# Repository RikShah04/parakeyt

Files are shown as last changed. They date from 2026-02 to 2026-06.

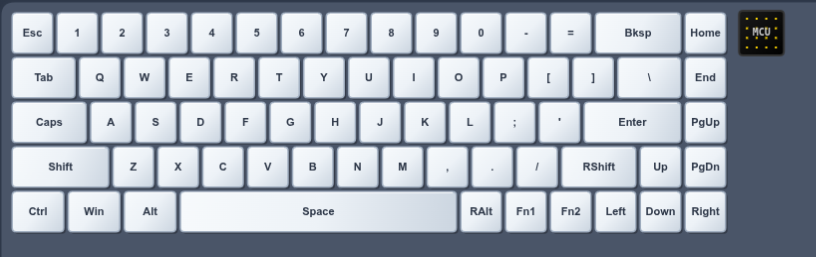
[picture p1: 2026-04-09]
example-boards/tkl/editor.png

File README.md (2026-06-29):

# parakeyt-docs
Ergonomic keyboard generator — PCB, firmware, and case file generation

# structure

## `reference-design/`
contains a completed reference design to act as a testing platform and schematic example of a potential parakeyt board.

it is hand designed, placed, and routed. it is not an actual output of the parakeyt toolchain.

# attribution
Footprints, models, symbols:
- RP2040-zero from https://github.com/crides/kleeb/ (MIT License)
- TLC59108IRGYR from manufacturer
- TLA2528IRTER from manufacturer
- AH49FNTR-G1 from manufacturer

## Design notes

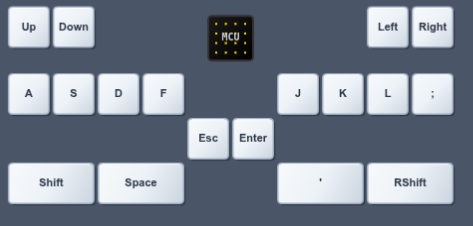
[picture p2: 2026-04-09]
example-boards/sdvx/sdvx.png

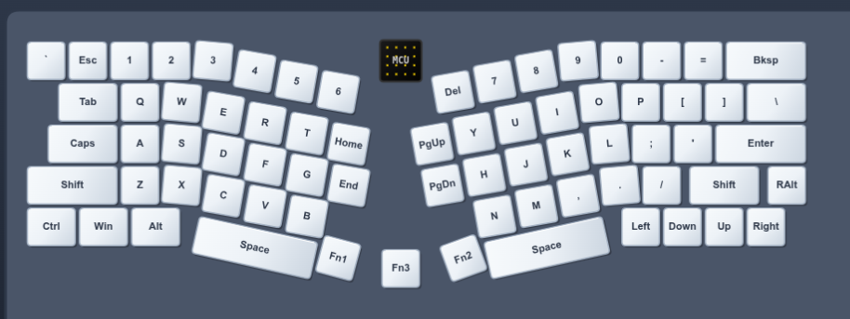
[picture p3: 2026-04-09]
example-boards/alice/alice.png

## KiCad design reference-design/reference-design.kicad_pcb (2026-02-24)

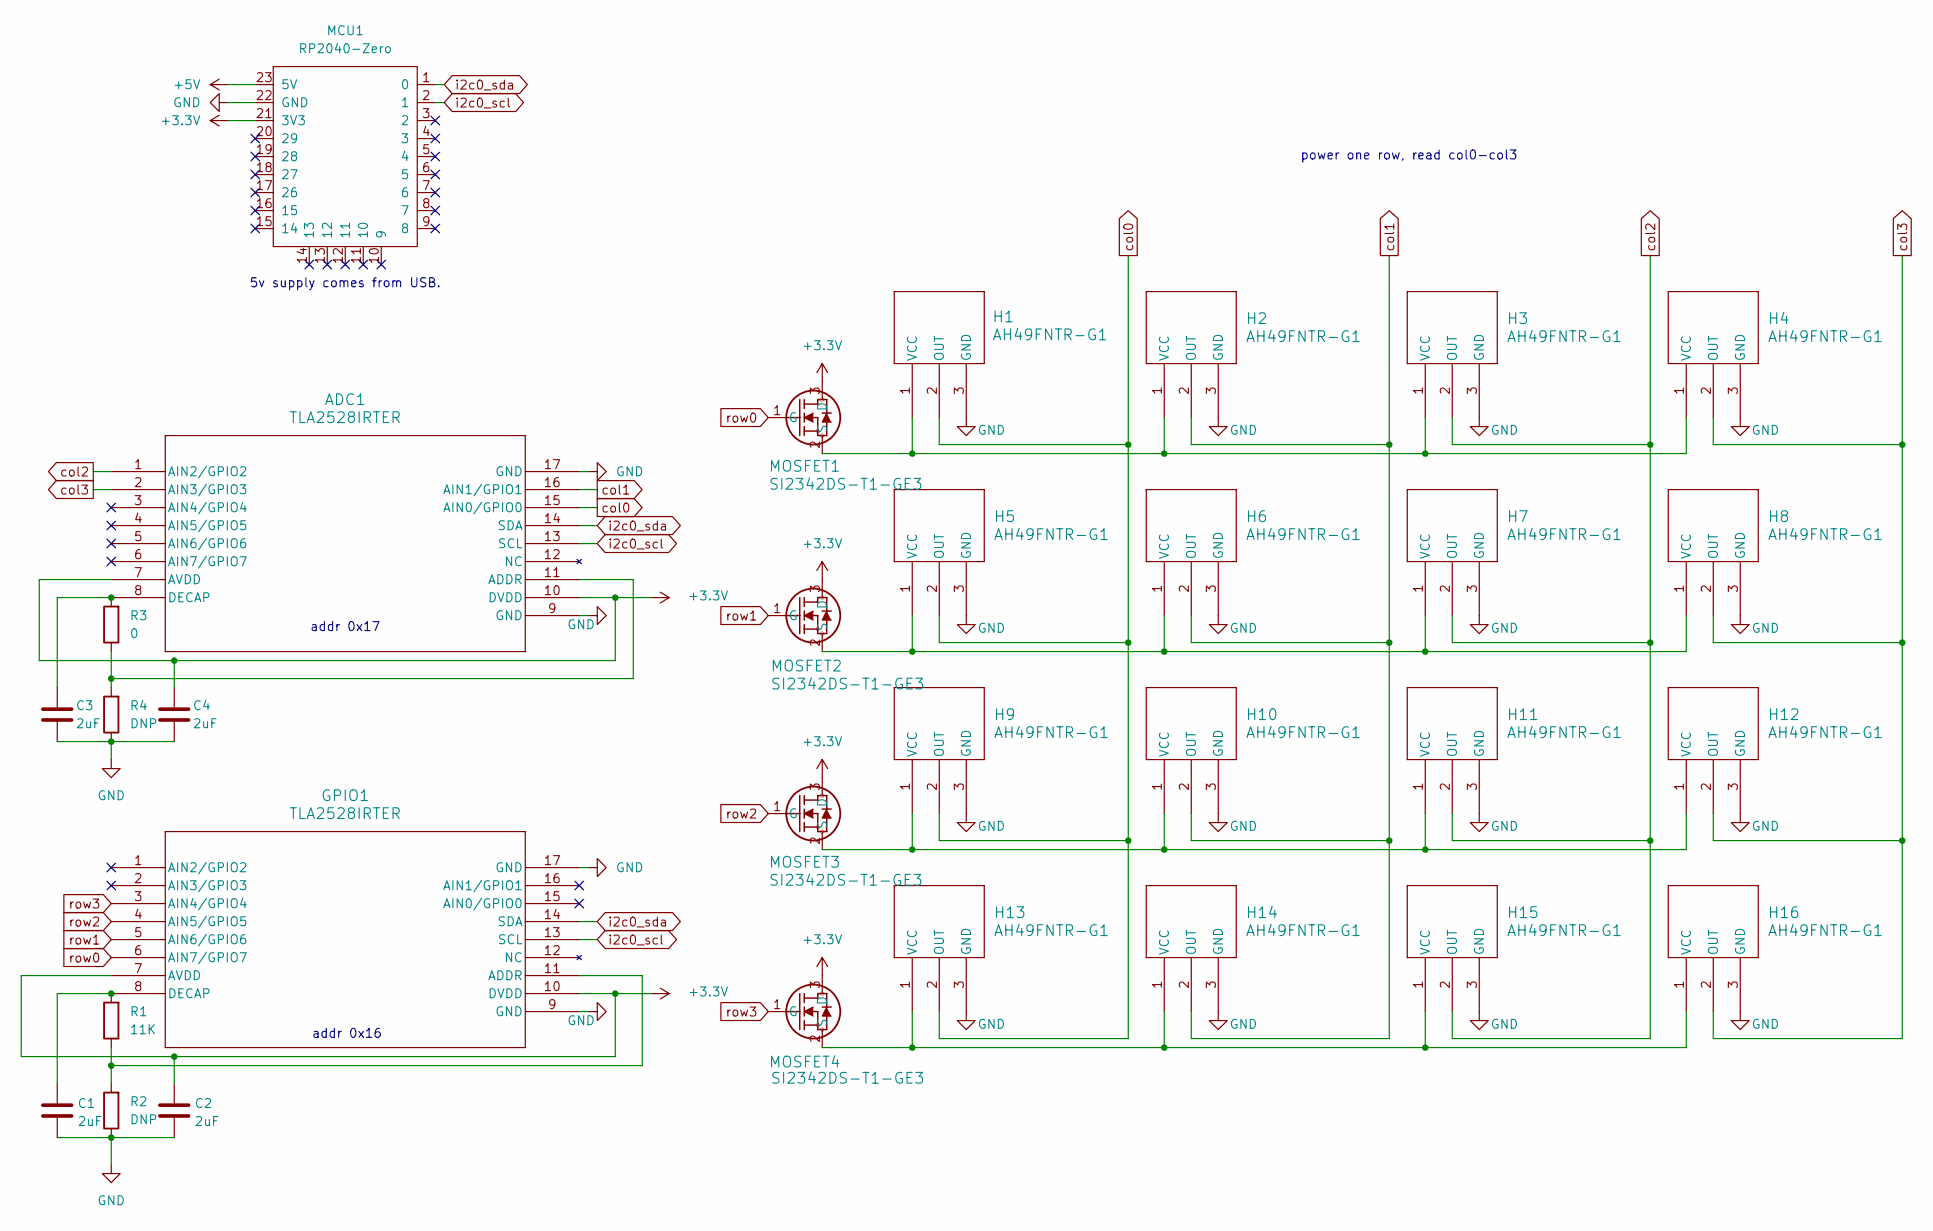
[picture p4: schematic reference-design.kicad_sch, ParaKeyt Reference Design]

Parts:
ADC1: TLA2528IRTER; WQFN16_RTE_TEX
C1, C2, C3, C4: 2uF; C_0603_1608Metric
GPIO1: TLA2528IRTER; WQFN16_RTE_TEX
H1, H2, H3, H4, H5, H6, H7, H8, H9, H10, H11, H12, H13, H14, H15, H16: AH49FNTR-G1; SC59_DIO
MCU1: RP2040-Zero; rp2040-zero-tht
MOSFET1, MOSFET2, MOSFET3, MOSFET4: SI2342DS-T1-GE3; SOT-23_TO-236_VIS
R1: 11K; R_0603_1608Metric
R2, R4: DNP; R_0603_1608Metric
R3: 0; R_0603_1608Metric

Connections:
+3.3V: ADC1.7 (AVDD), ADC1.10 (DVDD), C2.1, C4.1, GPIO1.7 (AVDD), GPIO1.10 (DVDD), MCU1.21 (3V3), MOSFET1.3 (D), MOSFET2.3 (D), MOSFET3.3 (D), MOSFET4.3 (D)
+5V: MCU1.23 (5V)
GND: ADC1.9 (GND), ADC1.17 (GND), C1.2, C2.2, C3.2, C4.2, GPIO1.9 (GND), GPIO1.17 (GND), H1.3 (GND), H2.3 (GND), H3.3 (GND), H4.3 (GND), H5.3 (GND), H6.3 (GND), H7.3 (GND), H8.3 (GND), H9.3 (GND), H10.3 (GND), H11.3 (GND), H12.3 (GND), H13.3 (GND), H14.3 (GND), H15.3 (GND), H16.3 (GND), MCU1.22 (GND), R2.1, R4.1
unnamed: ADC1.11 (ADDR), R3.1, R4.2
unnamed: ADC1.8 (DECAP), C3.1, R3.2
unnamed: GPIO1.11 (ADDR), R1.1, R2.2
unnamed: C1.1, GPIO1.8 (DECAP), R1.2
unnamed: H1.1 (VCC), H2.1 (VCC), H3.1 (VCC), H4.1 (VCC), MOSFET1.2 (S)
unnamed: H5.1 (VCC), H6.1 (VCC), H7.1 (VCC), H8.1 (VCC), MOSFET2.2 (S)
unnamed: H9.1 (VCC), H10.1 (VCC), H11.1 (VCC), H12.1 (VCC), MOSFET3.2 (S)
unnamed: H13.1 (VCC), H14.1 (VCC), H15.1 (VCC), H16.1 (VCC), MOSFET4.2 (S)
col0: ADC1.15 (AIN0/GPIO0), H1.2 (OUT), H5.2 (OUT), H9.2 (OUT), H13.2 (OUT)
col1: ADC1.16 (AIN1/GPIO1), H2.2 (OUT), H6.2 (OUT), H10.2 (OUT), H14.2 (OUT)
col2: ADC1.1 (AIN2/GPIO2), H3.2 (OUT), H7.2 (OUT), H11.2 (OUT), H15.2 (OUT)
col3: ADC1.2 (AIN3/GPIO3), H4.2 (OUT), H8.2 (OUT), H12.2 (OUT), H16.2 (OUT)
i2c0_scl: ADC1.13 (SCL), GPIO1.13 (SCL), MCU1.2 (1)
i2c0_sda: ADC1.14 (SDA), GPIO1.14 (SDA), MCU1.1 (0)
row0: GPIO1.6 (AIN7/GPIO7), MOSFET1.1 (G)
row1: GPIO1.5 (AIN6/GPIO6), MOSFET2.1 (G)
row2: GPIO1.4 (AIN5/GPIO5), MOSFET3.1 (G)
row3: GPIO1.3 (AIN4/GPIO4), MOSFET4.1 (G)

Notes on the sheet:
addr 0x16
addr 0x17
5v supply comes from USB.
power one row, read col0-col3

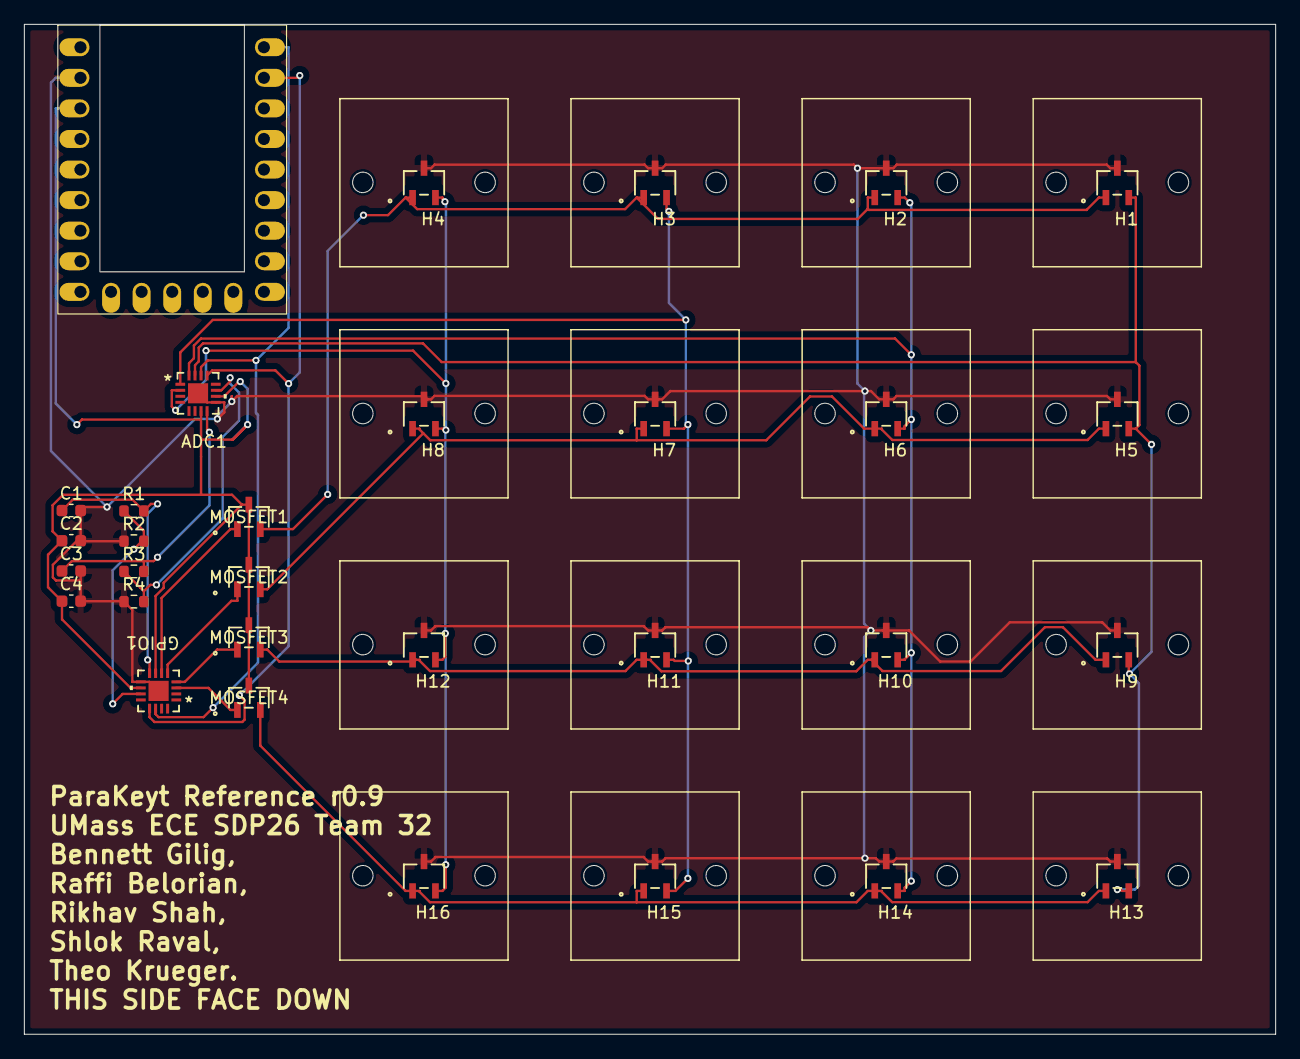
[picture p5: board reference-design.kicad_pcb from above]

Board: 2 copper layers, 104.0 x 83.9 mm, 31 parts (0 on the bottom side), 20 nets.

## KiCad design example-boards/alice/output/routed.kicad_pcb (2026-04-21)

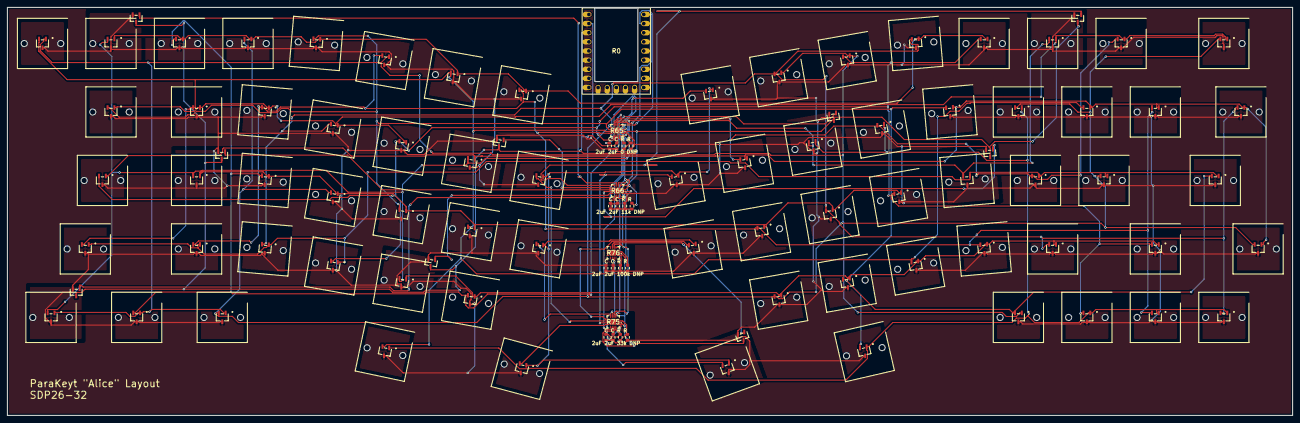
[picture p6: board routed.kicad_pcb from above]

Board: 2 copper layers, 357.5 x 113.5 mm, 76 parts (0 on the bottom side), 43 nets.

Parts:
R0: rp2040-zero-tht
R1, R9, R17, R25, R33, R41, R49, R57, R67: SC59_DIO_KeyswitchOutline_NoRuleArea_mosfet
R2, R3, R4, R5, R6, R7, R8, R10, R11, R12, R13, R14, R15, R16, R18, R19, R20, R21, R22, R23, R24, R26, R27, R28, R29, R30, R31, R32, R34, R35, R36, R37, R38, R39, R40, R42, R43, R44, R45, R46, R47, R48, R50, R51, R52, R53, R54, R55, R56, R58, R59, R60, R61, R62, R63, R64, R68, R69, R70, R71, R72, R74: SC59_DIO_KeyswitchOutline_NoRuleArea_mosfet; SC59_DIO_KeyswitchOutline_NoRuleArea
R65, R66, R75, R76: WQFN16_RTE_TEX_with_caps_and_Rs

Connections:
+3.3v: R0.21, R1.6, R9.6, R17.6, R25.6, R33.6, R41.6, R49.6, R57.6, R65.7, R65.10, R65.20, R66.7, R66.10, R67.6, R75.7, R75.10, R75.20, R76.7, R76.10
GND: R0.22, R1.3, R1.5, R2.3, R3.3, R4.3, R5.3, R6.3, R7.3, R8.3, R9.3, R9.5, R10.3, R11.3, R12.3, R13.3, R14.3, R15.3, R16.3, R17.3, R17.5, R18.3, R19.3, R20.3, R21.3, R22.3, R23.3, R24.3, R25.3, R25.5, R26.3, R27.3, R28.3, R29.3, R30.3, R31.3, R32.3, R33.3, R33.5, R34.3, R35.3, R36.3, R37.3, R38.3, R39.3, R40.3, R41.3, R41.5, R42.3, R43.3, R44.3, R45.3, R46.3, R47.3, R48.3, R49.3, R49.5, R50.3, R51.3, R52.3, R53.3, R54.3, R55.3, R56.3, R57.3, R57.5, R58.3, R59.3, R60.3, R61.3, R62.3, R63.3, R64.3, R65.9, R65.17, R65.19, R65.23, R66.9, R66.17, R66.18, R66.19, R66.20, R66.21, R66.22, R66.23, R67.3, R67.5, R68.3, R69.3, R70.3, R71.3, R72.3, R74.3, R75.9, R75.17, R75.19, R75.23, R76.9, R76.17, R76.18, R76.19, R76.20, R76.21, R76.22, R76.23
SCL: R0.2, R65.13, R66.13, R75.13, R76.13
SDA: R0.1, R65.14, R66.14, R75.14, R76.14
addr10: R65.11, R65.21, R65.24
addr11: R75.11, R75.21, R75.24
addr20: R66.11, R66.24
addr21: R76.11, R76.24
decap10: R65.8, R65.18, R65.22
decap11: R75.8, R75.18, R75.22
m0c0: R1.2, R9.2, R17.2, R25.2, R33.2, R41.2, R49.2, R57.2, R65.15
m0c1: R2.2, R10.2, R18.2, R26.2, R34.2, R42.2, R50.2, R58.2, R65.16
m0c2: R3.2, R11.2, R19.2, R27.2, R35.2, R43.2, R51.2, R59.2, R65.1
m0c3: R4.2, R12.2, R20.2, R28.2, R36.2, R44.2, R52.2, R60.2, R65.2
m0c4: R5.2, R13.2, R21.2, R29.2, R37.2, R45.2, R53.2, R61.2, R65.3
m0c5: R6.2, R14.2, R22.2, R30.2, R38.2, R46.2, R54.2, R62.2, R65.4
m0c6: R7.2, R15.2, R23.2, R31.2, R39.2, R47.2, R55.2, R63.2, R65.5
m0c7: R8.2, R16.2, R24.2, R32.2, R40.2, R48.2, R56.2, R64.2, R65.6
m0r0: R1.4, R66.15
m0r0MOS: R1.1, R2.1, R3.1, R4.1, R5.1, R6.1, R7.1, R8.1
m0r1: R9.4, R66.16
m0r1MOS: R9.1, R10.1, R11.1, R12.1, R13.1, R14.1, R15.1, R16.1
m0r2: R17.4, R66.1
m0r2MOS: R17.1, R18.1, R19.1, R20.1, R21.1, R22.1, R23.1, R24.1
m0r3: R25.4, R66.2
m0r3MOS: R25.1, R26.1, R27.1, R28.1, R29.1, R30.1, R31.1, R32.1
m0r4: R33.4, R66.3
m0r4MOS: R33.1, R34.1, R35.1, R36.1, R37.1, R38.1, R39.1, R40.1
m0r5: R41.4, R66.4
m0r5MOS: R41.1, R42.1, R43.1, R44.1, R45.1, R46.1, R47.1, R48.1
m0r6: R49.4, R66.5
m0r6MOS: R49.1, R50.1, R51.1, R52.1, R53.1, R54.1, R55.1, R56.1
m0r7: R57.4, R66.6
m0r7MOS: R57.1, R58.1, R59.1, R60.1, R61.1, R62.1, R63.1, R64.1
m1c0: R67.2, R75.15
m1c1: R68.2, R75.16
m1c2: R69.2, R75.1
m1c3: R70.2, R75.2
m1c4: R71.2, R75.3
m1c5: R72.2, R75.4
m1c7: R74.2, R75.6
m1r0: R67.4, R76.15
m1r0MOS: R67.1, R68.1, R69.1, R70.1, R71.1, R72.1, R74.1

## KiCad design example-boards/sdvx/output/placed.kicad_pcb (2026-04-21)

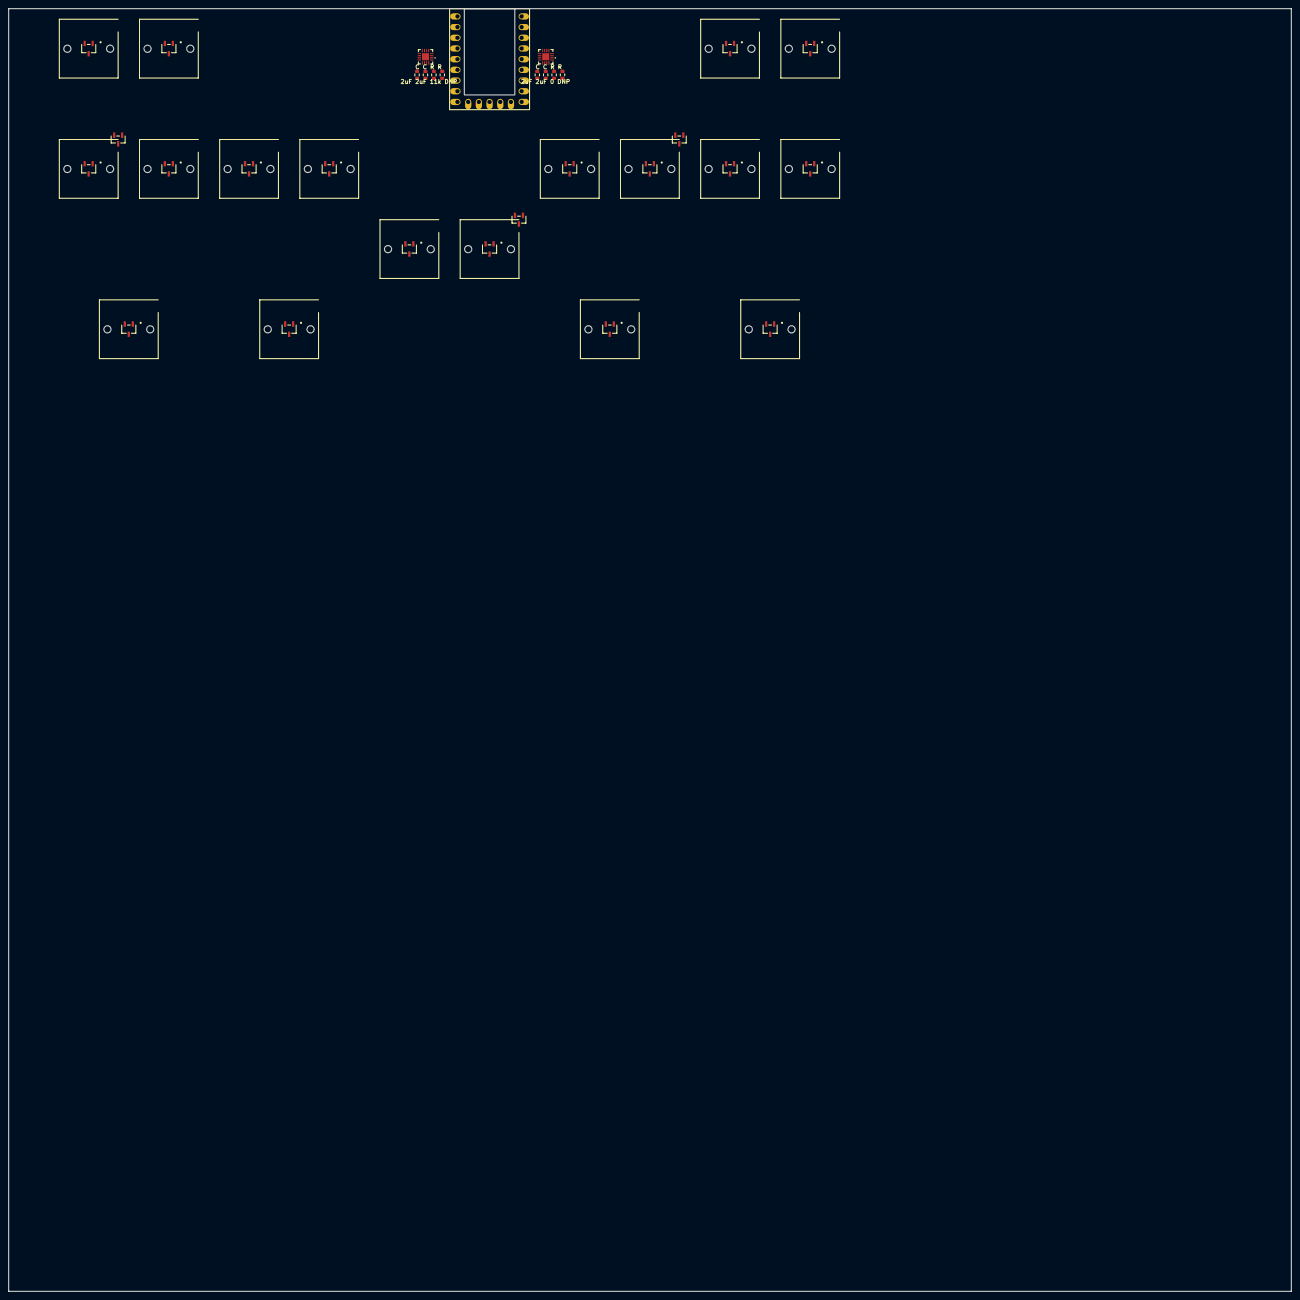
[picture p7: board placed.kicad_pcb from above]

Board: 2 copper layers, 304.8 x 304.8 mm, 21 parts (0 on the bottom side), 21 nets, no tracks yet.

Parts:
R0: rp2040-zero-tht
R1, R9, R17: SC59_DIO_KeyswitchOutline_NoRuleArea_mosfet
R2, R3, R4, R5, R6, R7, R8, R10, R11, R12, R13, R14, R15, R16, R18: SC59_DIO_KeyswitchOutline_NoRuleArea_mosfet; SC59_DIO_KeyswitchOutline_NoRuleArea
R19, R20: WQFN16_RTE_TEX_with_caps_and_Rs

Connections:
+3.3v: R0.21, R1.6, R9.6, R17.6, R19.7, R19.10, R19.20, R20.7, R20.10
GND: R0.22, R1.3, R1.5, R2.3, R3.3, R4.3, R5.3, R6.3, R7.3, R8.3, R9.3, R9.5, R10.3, R11.3, R12.3, R13.3, R14.3, R15.3, R16.3, R17.3, R17.5, R18.3, R19.9, R19.17, R19.19, R19.23, R20.9, R20.17, R20.18, R20.19, R20.20, R20.21, R20.22, R20.23
SCL: R0.2, R19.13, R20.13
SDA: R0.1, R19.14, R20.14
addr10: R19.11, R19.21, R19.24
addr20: R20.11, R20.24
decap10: R19.8, R19.18, R19.22
m0c0: R1.2, R9.2, R17.2, R19.15
m0c1: R2.2, R10.2, R18.2, R19.16
m0c2: R3.2, R11.2, R19.1
m0c3: R4.2, R12.2, R19.2
m0c4: R5.2, R13.2, R19.3
m0c5: R6.2, R14.2, R19.4
m0c6: R7.2, R15.2, R19.5
m0c7: R8.2, R16.2, R19.6
m0r0: R1.4, R20.15
m0r0MOS: R1.1, R2.1, R3.1, R4.1, R5.1, R6.1, R7.1, R8.1
m0r1: R9.4, R20.16
m0r1MOS: R9.1, R10.1, R11.1, R12.1, R13.1, R14.1, R15.1, R16.1
m0r2: R17.4, R20.1
m0r2MOS: R17.1, R18.1

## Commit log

2026-01-22 reference design PCBs unrouted
    needed for testing autorouter
    [reference-design_unrouted.kicad_pcb]
2026-02-17 replace led driver with another ADC (to be used as gpio to drive MOSFETs)
    [reference-design.kicad_pcb, reference-design.kicad_sch, reference-design_unrouted.kicad_pcb]
2026-02-17 add rp2040 cutout and keyswitch outlines
    [reference-design.kicad_pcb]
2026-02-19 why was this file here oopsies
    [reference_design.kicad_sch]
2026-02-24 prep for order
    [reference-design.kicad_pcb]
2026-04-21 lots of stuff
    [placed.kicad_pcb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]
